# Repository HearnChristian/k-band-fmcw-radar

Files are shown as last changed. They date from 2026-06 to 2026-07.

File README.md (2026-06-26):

# K-Band FMCW Radar

A frequency-modulated continuous-wave (FMCW) radar front-end designed in KiCad —
a single-board transceiver intended for **ground-based ranging and weather /
precipitation sensing**. This repository holds the schematic capture, the
project's custom KiCad libraries, and the generated netlist. Work in progress.

## Architecture

FMCW radar works by transmitting a continuous tone whose frequency is swept
(chirped) linearly in time, then mixing the received echo against the
transmitted signal. The frequency of the resulting beat tone is proportional to
target range, so the whole signal chain is built around generating a clean,
linear chirp and digitizing the low-frequency beat note.

```
  Reference        Chirp synth        RF transceiver        Driver amp
  ┌────────┐      ┌──────────┐       ┌──────────────┐      ┌──────────┐
  │  TCXO  │─────▶│ ADF4159  │──────▶│ BGT24LTR11N16│─────▶│AMM-8211PSM│──▶ TX
  │ ref clk│      │ PLL/ramp │       │ 24 GHz Tx/Rx │      │ driver PA │
  └────────┘      └──────────┘       └──────┬───────┘      └──────────┘
                                            │ IF (beat)
                                            ▼
                       ┌──────────┐   ┌──────────┐   ┌──────────┐
                  Rx ──│ OPA1656  │──▶│ ADS8353  │──▶│ FT2232H  │──▶ USB host
                       │ IF amp   │   │ 16b ADC  │   │ USB 2.0  │
                       └──────────┘   └──────────┘   └──────────┘
```

## Key components

| Block | Part | Function |
|---|---|---|
| Chirp synthesizer | **ADF4159** | Fractional-N PLL with onboard ramp generator — produces the linear FMCW sweep |
| RF transceiver | **BGT24LTR11N16** | 24 GHz SiGe transmit/receive front-end with integrated VCO and downconversion |
| Driver amplifier | **AMM-8211PSM** | 22–57 GHz GaAs MMIC driver amp boosting the transmit chain |
| IF / baseband | **OPA1656** | Low-noise, low-distortion op-amp conditioning the beat-note signal |
| Data converter | **ADS8353** | Dual 16-bit SAR ADC sampling the IF |
| Host interface | **FT2232HL** | USB 2.0 bridge for control + data streaming |
| Reference clock | **ECS-TXO-2520MV** | TCXO frequency reference |
| Power | **TPS7A4700 / TPS7A2018 / TPS7A2033** | Ultra-low-noise LDOs for clean RF/analog rails |
| Config | **93LC56B** | EEPROM for FT2232 descriptor |

## Custom library work

The **AMM-8211PSM** driver amplifier had no vendor-supplied EDA data — only a
datasheet — so its schematic symbol and PCB footprint were built from scratch
from the Marki Microwave mechanical drawings:

```
AMM-8211PSM.kicad_sym                                          custom symbol
AMM-8211PSM.pretty/QFN-16-1EP_3x3mm_P0.5mm_EP1.1x1.1mm_Marki.kicad_mod   custom footprint
```

The footprint is a 3 × 3 mm 16-lead QFN, 0.5 mm pitch, with a 1.10 × 1.10 mm
exposed ground paddle and a 3 × 3 array of thermal vias, matching the Marki
outline drawing and pin assignment.

## Repository layout

```
Radar1.kicad_pro      KiCad project
Radar1.kicad_sch      Schematic (in progress)
Radar1.kicad_pcb      PCB layout (not yet started)
Radar1.net            Exported netlist
AMM-8211PSM.kicad_sym Custom symbol (see above)
AMM-8211PSM.pretty/   Custom footprint library
sym-lib-table         Project symbol-library table
fp-lib-table          Project footprint-library table
```

## Tools

Designed in [KiCad](https://www.kicad.org/) 9. Open `Radar1.kicad_pro` to view
the schematic.

---

*Author: Christian Hearn*

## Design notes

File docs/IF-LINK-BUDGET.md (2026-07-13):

# IF Gain vs Link Budget (Rev-F)

Sizing the OPA1656 IF stage between the BGT24LTR11 mixer and the ADS8353
(pseudo-diff vs VREF = 2.5 V, FS = ±2.5 V pk). Reproduce with
`tools/if_link_budget.py`.

## Assumptions

+6 dBm TX (BGT24 typ), 10 dBi per antenna, 1 dB per cable, 250 MHz / 1 ms
chirp (beat = 1.667 kHz/m, FFT bin 1 kHz), mixer Gc 20 dB / NF 10 dB SSB /
IP1dB −28 dBm (DS Table 4), anti-alias 49.9 Ω + 10 nF = 319 kHz.

## Gain choice: ×19 (R13/R16 = 18k, Rg = 1k)

The mixer compresses at −28 dBm input → 126 mVpk at its output. Gain
×19.9 maps that exactly onto ADC full scale, so the converter clips only
when the mixer itself is already compressing — no wasted ADC range, no
ADC-first clipping. E24 choice **×19 = 25.6 dB** (was ×11 placeholder,
which left ~5 dB of ADC range unusable).

Noise: chain noise at the ADC is 190 µVrms (269 nV/√Hz over the AA band)
vs ~44 µVrms ADC noise → solidly thermal-limited; sensitivity is set at
the mixer input and is independent of this gain within reason.

## Coupling corner: C36/C37 100 nF → 560 pF

Into the 100 kΩ VREF bias the old corner was **16 Hz** — passing the TX
leakage beat and closest clutter at full gain, which would dominate the
ADC range. 560 pF puts the corner at **2.8 kHz ≈ 1.7 m** minimum range;
the single pole also provides mild R⁴ compensation below the corner.

## Performance (per 1 kHz bin, 13 dB detection)

| Target | Range | Beat | ADC level (×19) | SNR/bin |
|---|---|---|---|---|
| person (1 m²) | 10 m | 17 kHz | 2.7 mVpk | 47 dB |
| person | 30 m | 50 kHz | 295 µVpk | 28 dB |
| car (10 m²) | 50 m | 83 kHz | 336 µVpk | 29 dB |
| car | 100 m | 167 kHz | 84 µVpk | 17 dB |
| car | 150 m | 250 kHz | 37 µVpk | 10 dB |

Detection range ≈ **70 m (person) / 125 m (car)**; the anti-alias corner
caps the instrumented range at 191 m. Sample both ADC channels at
≥640 kSPS (ADS8353 supports 700 kSPS dual).

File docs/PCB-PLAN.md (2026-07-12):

# PCB Plan — Stackup Trade & Floorplan (pre-layout)

Base: schematic `21be641` (electrically identical to Rev-C `4aef776`, netlist-verified).
Date: 2026-07-09.

## Substrate decision

Only the three 24 GHz runs (TX chain to J3, RX feed from J4) and the 1.5 GHz
divided LO care about the substrate; everything else is DC/SPI/IF.

| Option | Dk | tan δ | ~Loss @24 GHz | Z₀ tol | Verdict |
|---|---|---|---|---|---|
| All FR4 | 4.2–4.6 (uncontrolled) | ~0.020 | 0.5–0.8 dB/cm | ±8–10 % | Reject — loss + Dk uncertainty eat the PA gain budget |
| **Hybrid RO4350B (10 mil) over FR4** | 3.48 ± 0.05 | 0.0037 | 0.10–0.15 dB/cm | ±2–3 % | **Pick** — all RF is on L1/L2; FR4 below carries power/digital |
| Full RO4350B | 3.48 ± 0.05 | 0.0037 | 0.10–0.15 dB/cm | ±2–3 % | Overkill — inner layers are DC/digital |

**Stackup (≈1.5 mm, ENIG):** L1 RF/signal — RO4350B 0.254 mm — L2 solid GND —
FR4 core ≈0.9 mm — L3 power — prepreg — L4 signal/GND.
50 Ω GCPW starting point: w ≈ 0.50 mm, gap ≈ 0.25 mm (field-solve against fab stackup).

## Floorplan (board ≈ 66 × 46 mm)

- **West edge:** J3 (TX) / J4 (RX) end-launch, ≥26.5 GHz rated (2.92 mm preferred).
  U12 PA driver between U1 and J3; U1 BGT24 center-west. 24 GHz GCPW with via
  fences (pitch ≤ 0.8 mm) both sides; stitching ring around RF zone.
- **PLL:** U2 ADF4159 east of U1; loop filter tight, guarded, nothing switching
  within 5 mm; Y1 50 MHz TCXO short/direct into REFIN.
- **Center:** IF chain U1 → U3 (OPA1656 ×3) → U8 ADS8353; U15 REF5025 adjacent.
- **East edge:** U7 FT2232H, U11 12 MHz, U10 EEPROM, J1 USB-C.
- **South strip:** J2 barrel (SE) → U6 5 V LDO (+ thermal pour) → LDO row.
  U9 ADP5600 (−VGG charge pump, the only switcher) far corner from RX, LC
  post-filter to PA gate. +3V3_RF / +3V3_DIG copper split mirrors the Rev-C rail split.
- Thermal: EP via arrays under U1, U12, U6, U13.

## Blockers before placement

1. **CRITICAL — ADF4159 SPI overvoltage.** FT2232H drives CLK/DATA/LE/CE/TXDATA
   at 3.3 V; ADF4159 digital abs-max = DVDD + 0.3 V = 2.1 V (datasheet Table 4).
   MUXOUT readback (1.8 V logic → 3.3 V-bank input) is marginal in reverse.
   Fix (no new parts): power FT2232H ADBUS-bank VCCIO from +1V8 (VCCIO spec
   1.62–3.63 V), and move ADS8353 DVDD from +3V3_RF to +1V8 (also removes ADC
   digital noise from the RF rail).
2. Footprint pass: ~12 symbols unassigned; 5 libs missing from `fp-lib-table`.
3. Sync embedded symbols with libs (USB4215-03-A, AMM-8211PSM mismatch).
4. Spec barrel input 6 V nominal (≤6.5 V) or add buck before U6 — LDO drops
   (VIN−5 V) × ~0.45 A.
5. Optional: route U1 V_PTAT to a spare ADC channel for temperature telemetry.

## Verified correct in this review

PA sequencing (ADP5600 PGOOD gates +3V0_PA enable), PA bias (Vd = 3 V/175 mA =
datasheet nominal), TPS7A4700 straps (5.0 V / 3.0 V exact), FT2232 VCORE loop,
ADF4159 rail split (AVDD 3.3 / DVDD 1.8). ERC "errors" are symbol pin-type
pedantry; netlist has no floating nets.

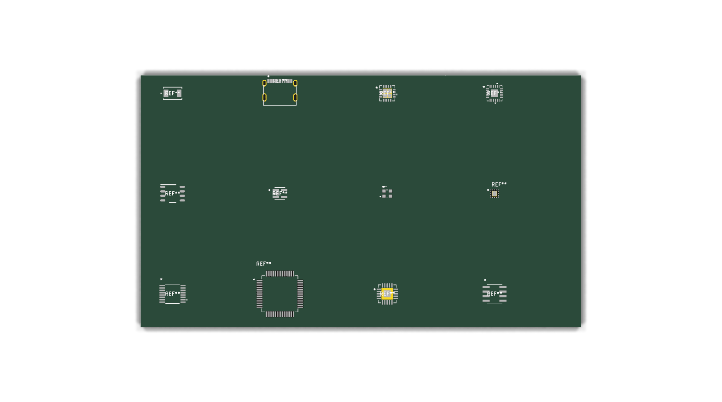
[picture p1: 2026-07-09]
docs/footprints-preview.png

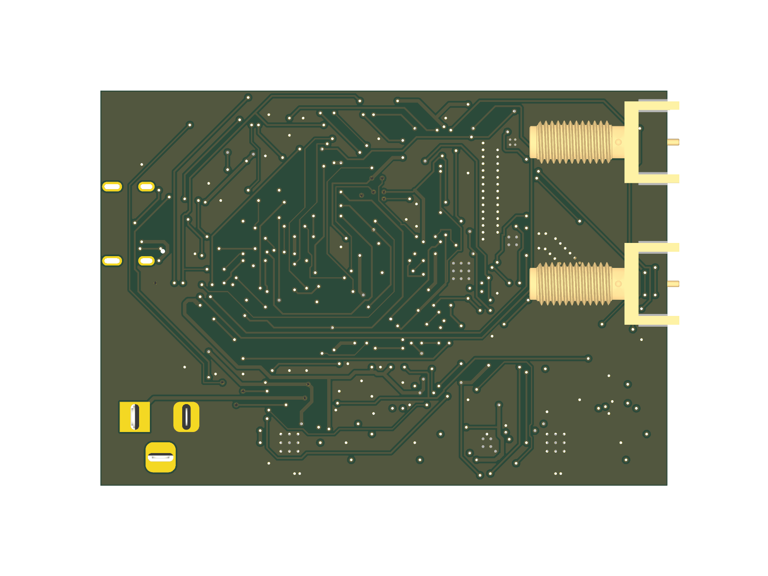
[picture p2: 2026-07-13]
docs/board-bottom.png

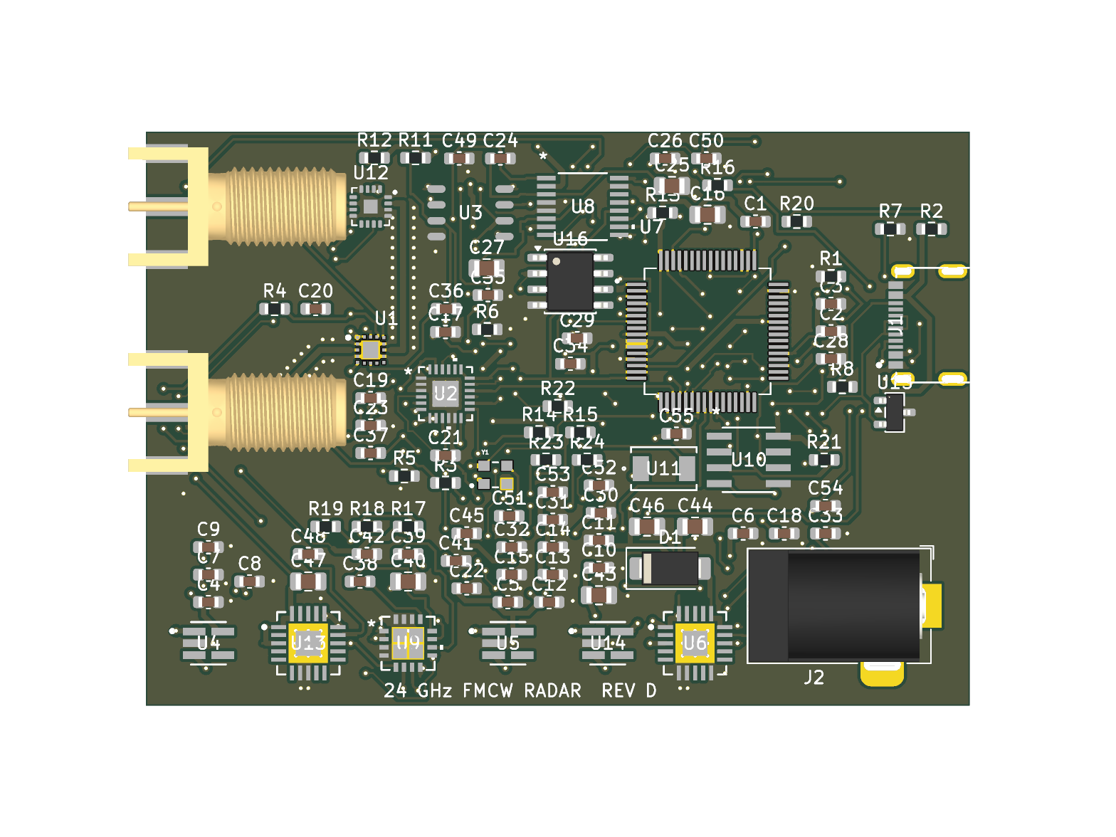
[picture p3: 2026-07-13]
docs/board-top.png

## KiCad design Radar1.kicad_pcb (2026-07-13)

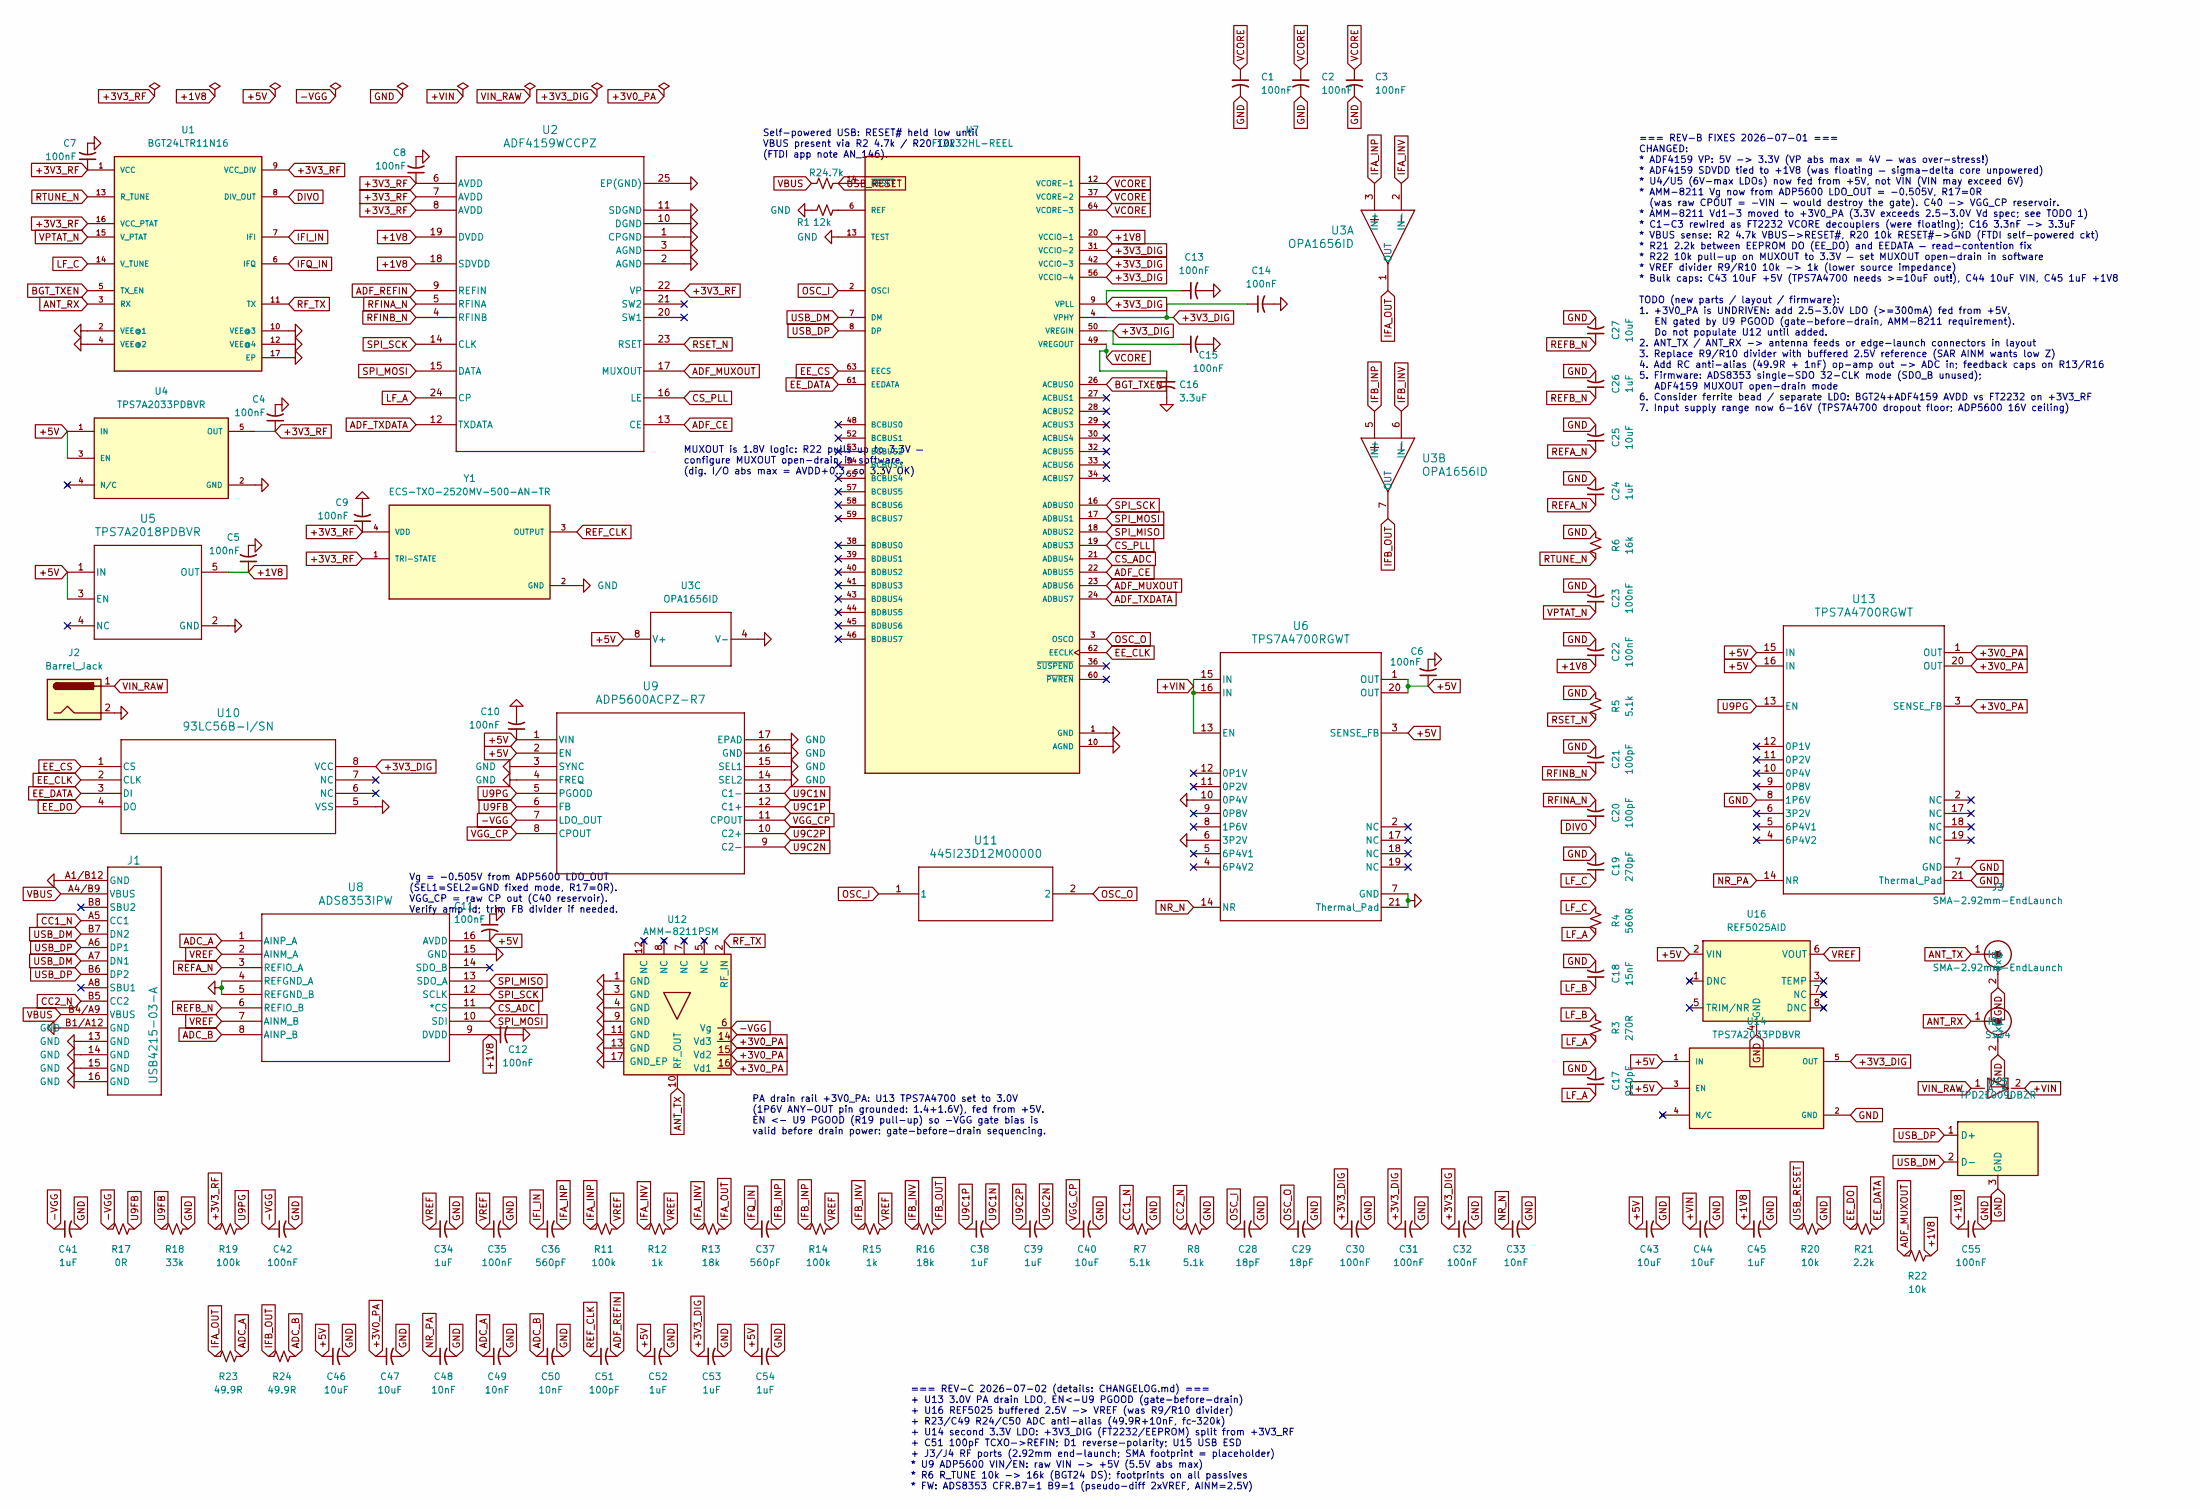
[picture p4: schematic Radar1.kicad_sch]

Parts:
C1, C2, C3, C4, C5, C6, C7, C8, C9, C10, C11, C12, C13, C14, C15, C22, C23, C30, C31, C32, C35, C42, C55: 100nF; C_0603_1608Metric
C16: 3.3uF; C_0805_2012Metric
C17: 910pF; C_0603_1608Metric
C18: 15nF; C_0603_1608Metric
C19: 270pF; C_0603_1608Metric
C20, C21, C51: 100pF; C_0603_1608Metric
C24, C26, C34, C38, C39, C41, C45, C52, C53, C54: 1uF; C_0603_1608Metric
C25, C27, C40, C43, C44, C46, C47: 10uF; C_0805_2012Metric
C28, C29: 18pF; C_0603_1608Metric
C33, C48, C49, C50: 10nF; C_0603_1608Metric
C36, C37: 560pF; C_0603_1608Metric
D1: SS34; D_SMA
J1: USB4215-03-A; CONN_8p94X6p5X3p16_12L_GCC
J2: Barrel_Jack; BarrelJack_Horizontal
J3, J4: SMA-2.92mm-EndLaunch; SMA_Amphenol_132289_EdgeMount
R1: 12k; R_0603_1608Metric
R2: 4.7k; R_0603_1608Metric
R3: 270R; R_0603_1608Metric
R4: 560R; R_0603_1608Metric
R5, R7, R8: 5.1k; R_0603_1608Metric
R6: 16k; R_0603_1608Metric
R11, R14, R19: 100k; R_0603_1608Metric
R12, R15: 1k; R_0603_1608Metric
R13, R16: 18k; R_0603_1608Metric
R17: 0R; R_0603_1608Metric
R18: 33k; R_0603_1608Metric
R20, R22: 10k; R_0603_1608Metric
R21: 2.2k; R_0603_1608Metric
R23, R24: 49.9R; R_0603_1608Metric
U1: BGT24LTR11N16; PQFN50P240X240X77-17N-V
U2: ADF4159WCCPZ; CP_24_10
U3: OPA1656ID; D0008A_N
U4, U14: TPS7A2033PDBVR; DBV0005A-IPC_A; PARTREV H
U5: TPS7A2018PDBVR; DBV0005A-IPC_A
U6, U13: TPS7A4700RGWT; RGW0020A-IPC_A
U7: FT2232HL-REEL; QFP50P1200X1200X160-64N
U8: ADS8353IPW; PW16_TEX
U9: ADP5600ACPZ-R7; CP-16-17_ADI
U10: 93LC56B-I/SN; SOIC8-N_MC_MCH
U11: 445I23D12M00000; 445I23D12M00000_CTS
U12: AMM-8211PSM; QFN-16-1EP_3x3mm_P0.5mm_EP1.1x1.1mm_Marki; MPN AMM-8211PSM-22
U15: TPD2E009DBZR; SOT-23
U16: REF5025AID; SOIC-8_3.9x4.9mm_P1.27mm
Y1: ECS-TXO-2520MV-500-AN-TR; OSC_ECS-TXO-2520MV-500-AN-TR; PARTREV 2017

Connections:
+1V8: C5.1, C12.1, C22.1, C45.1, C55.1, R22.2, U2.18 (SDVDD), U2.19 (DVDD), U5.5 (OUT), U7.20 (VCCIO-1), U8.9 (DVDD)
+3V0_PA: C47.1, U12.14 (Vd3), U12.15 (Vd2), U12.16 (Vd1), U13.1 (OUT), U13.3 (SENSE_FB), U13.20 (OUT)
+3V3_DIG: C13.1, C14.1, C15.1, C30.1, C31.1, C32.1, C53.1, U7.4 (VPHY), U7.9 (VPLL), U7.31 (VCCIO-2), U7.42 (VCCIO-3), U7.50 (VREGIN), U7.56 (VCCIO-4), U10.8 (VCC), U14.5 (OUT)
+3V3_RF: C4.1, C7.1, C8.1, C9.1, R19.1, U1.1 (VCC), U1.9 (VCC_DIV), U1.16 (VCC_PTAT), U2.6 (AVDD), U2.7 (AVDD), U2.8 (AVDD), U2.22 (VP), U4.5 (OUT), Y1.1 (TRI-STATE), Y1.4 (VDD)
+5V: C6.1, C10.1, C11.2, C43.1, C46.1, C52.1, C54.1, U3.8 (V+), U4.1 (IN), U4.3 (EN), U5.1 (IN), U5.3 (EN), U6.1 (OUT), U6.3 (SENSE_FB), U6.20 (OUT), U8.16 (AVDD), U9.1 (VIN), U9.2 (EN), U13.15 (IN), U13.16 (IN), U14.1 (IN), U14.3 (EN), U16.2 (VIN)
+VIN: C44.1, D1.2 (K), U6.13 (EN), U6.15 (IN), U6.16 (IN)
-VGG: C41.1, C42.1, R17.1, U9.7 (LDO_OUT), U12.6 (Vg)
ADC_A: C49.1, R23.2, U8.1 (AINP_A)
ADC_B: C50.1, R24.2, U8.8 (AINP_B)
ADF_CE: U2.13 (CE), U7.22 (ADBUS5)
ADF_MUXOUT: R22.1, U2.17 (MUXOUT), U7.23 (ADBUS6)
ADF_REFIN: C51.2, U2.9 (REFIN)
ADF_TXDATA: U2.12 (TXDATA), U7.24 (ADBUS7)
ANT_RX: J4.1 (In), U1.3 (RX)
ANT_TX: J3.1 (In), U12.10 (RF_OUT)
BGT_TXEN: U1.5 (TX_EN), U7.26 (ACBUS0)
CC1_N: J1.A5 (CC1), R7.1
CC2_N: J1.B5 (CC2), R8.1
CS_ADC: U7.21 (ADBUS4), U8.11 (*CS)
CS_PLL: U2.16 (LE), U7.19 (ADBUS3)
DIVO: C20.1, U1.8 (DIV_OUT)
EE_CLK: U7.62 (EECLK), U10.2 (CLK)
EE_CS: U7.63 (EECS), U10.1 (CS)
EE_DATA: R21.2, U7.61 (EEDATA), U10.3 (DI)
EE_DO: R21.1, U10.4 (DO)
GND: C1.2, C2.2, C3.2, C4.2, C5.2, C6.2, C7.2, C8.2, C9.2, C10.2, C11.1, C12.2, C13.2, C14.2, C15.2, C16.2, C17.2, C18.2, C19.2, C21.2, C22.2, C23.2, C24.2, C25.2, C26.2, C27.2, C28.2, C29.2, C30.2, C31.2, C32.2, C33.2, C34.2, C35.2, C40.2, C41.2, C42.2, C43.2, C44.2, C45.2, C46.2, C47.2, C48.2, C49.2, C50.2, C52.2, C53.2, C54.2, C55.2, J1.13 (GND), J1.14 (GND), J1.15 (GND), J1.16 (GND), J1.A1/B12 (GND), J1.B1/A12 (GND), J2.2, J3.2 (Ext), J4.2 (Ext), R1.1, R5.2, R6.2, R7.2, R8.2, R18.2, R20.2, U1.2 (VEE@1), U1.4 (VEE@2), U1.10 (VEE@3), U1.12 (VEE@4), U1.17 (EP), U2.1 (CPGND), U2.2 (AGND), U2.3 (AGND), U2.10 (DGND), U2.11 (SDGND), U2.25 (EP(GND)), U3.4 (V-), U4.2 (GND), U5.2 (GND), U6.6 (3P2V), U6.7 (GND), U6.10 (0P4V), U6.21 (Thermal_Pad), U7.1 (GND), U7.5 (GND), U7.10 (AGND), U7.11 (GND), U7.13 (TEST), U7.15 (GND), U7.25 (GND), U7.35 (GND), U7.47 (GND), U7.51 (GND), U8.4 (REFGND_A), U8.5 (REFGND_B), U8.15 (GND), U9.3 (SYNC), U9.4 (FREQ), U9.14 (SEL2), U9.15 (SEL1), U9.16 (GND), U9.17 (EPAD), U10.5 (VSS), U12.1 (GND), U12.3 (GND), U12.4 (GND), U12.9 (GND), U12.11 (GND), U12.13 (GND), U12.17 (GND_EP), U13.7 (GND), U13.8 (1P6V), U13.21 (Thermal_Pad), U14.2 (GND), U15.3 (GND), U16.4 (GND), Y1.2 (GND)
IFA_INP: C36.2, R11.1, U3.3 (IN+)
IFA_INV: R12.1, R13.1, U3.2 (IN-)
IFA_OUT: R13.2, R23.1, U3.1 (OUT)
IFB_INP: C37.2, R14.1, U3.5 (IN+)
IFB_INV: R15.1, R16.1, U3.6 (IN-)
IFB_OUT: R16.2, R24.1, U3.7 (OUT)
IFI_IN: C36.1, U1.7 (IFI)
IFQ_IN: C37.1, U1.6 (IFQ)
LF_A: C17.1, R3.1, R4.1, U2.24 (CP)
LF_B: C18.1, R3.2
LF_C: C19.1, R4.2, U1.14 (V_TUNE)
NR_N: C33.1, U6.14 (NR)
NR_PA: C48.1, U13.14 (NR)
unnamed: R1.2, U7.6 (REF)
OSC_I: C28.1, U7.2 (OSCI), U11.1
OSC_O: C29.1, U7.3 (OSCO), U11.2
REFA_N: C24.1, C25.1, U8.3 (REFIO_A)
REFB_N: C26.1, C27.1, U8.6 (REFIO_B)
REF_CLK: C51.1, Y1.3 (OUTPUT)
RFINA_N: C20.2, U2.5 (RFINA)
RFINB_N: C21.1, U2.4 (RFINB)
RF_TX: U1.11 (TX), U12.2 (RF_IN)
RSET_N: R5.1, U2.23 (RSET)
RTUNE_N: R6.1, U1.13 (R_TUNE)
SPI_MISO: U7.18 (ADBUS2), U8.13 (SDO_A)
SPI_MOSI: U2.15 (DATA), U7.17 (ADBUS1), U8.10 (SDI)
SPI_SCK: U2.14 (CLK), U7.16 (ADBUS0), U8.12 (SCLK)
U9C1N: C38.2, U9.13 (C1-)
U9C1P: C38.1, U9.12 (C1+)
U9C2N: C39.2, U9.9 (C2-)
U9C2P: C39.1, U9.10 (C2+)
U9FB: R17.2, R18.1, U9.6 (FB)
U9PG: R19.2, U9.5 (PGOOD), U13.13 (EN)
USB_DM: J1.A7 (DN1), J1.B7 (DN2), U7.7 (DM), U15.2 (D-)
USB_DP: J1.A6 (DP1), J1.B6 (DP2), U7.8 (DP), U15.1 (D+)
USB_RESET: R2.2, R20.1, U7.14 (~RESET)
VBUS: J1.A4/B9 (VBUS), J1.B4/A9 (VBUS), R2.1
VCORE: C1.1, C2.1, C3.1, C16.1, U7.12 (VCORE-1), U7.37 (VCORE-2), U7.49 (VREGOUT), U7.64 (VCORE-3)
VGG_CP: C40.1, U9.8 (CPOUT), U9.11 (CPOUT)
VIN_RAW: D1.1 (A), J2.1
VPTAT_N: C23.1, U1.15 (V_PTAT)
VREF: C34.1, C35.1, R11.2, R12.2, R14.2, R15.2, U8.2 (AINM_A), U8.7 (AINM_B), U16.6 (VOUT)

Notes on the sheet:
Vg = -0.505V from ADP5600 LDO_OUT (SEL1=SEL2=GND fixed mode, R17=0R). VGG_CP = raw CP out (C40 reservoir). Verify amp Id; trim FB divider if needed.
=== REV-C 2026-07-02 (details: CHANGELOG.md) === + U13 3.0V PA drain LDO, EN<-U9 PGOOD (gate-before-drain) + U16 REF5025 buffered 2.5V -> VREF (was R9/R10 divider) + R23/C49 R24/C50 ADC anti-alias (49.9R+10nF, fc~320k) + U14 second 3.3V LDO: +3V3_DIG (FT2232/EEPROM) split from +3V3_RF + C51 100pF T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
Self-powered USB: RESET# held low until VBUS present via R2 4.7k / R20 10k (FTDI app note AN_146).
=== REV-B FIXES 2026-07-01 === CHANGED: * ADF4159 VP: 5V -> 3.3V (VP abs max = 4V — was over-stress!) * ADF4159 SDVDD tied to +1V8 (was floating — sigma-delta core unpowered) * U4/U5 (6V-max LDOs) now fed from +5V, not VIN (VIN may exceed 6V) * AMM-8211 Vg now from ADP5600 LDO_OUT = -0.505V, R17=0R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
MUXOUT is 1.8V logic: R22 pulls up to 3.3V — configure MUXOUT open-drain in software. (dig. I/O abs max = AVDD+0.3, so 3.3V OK)
PA drain rail +3V0_PA: U13 TPS7A4700 set to 3.0V (1P6V ANY-OUT pin grounded: 1.4+1.6V), fed from +5V. EN <- U9 PGOOD (R19 pull-up) so -VGG gate bias is valid before drain power: gate-before-drain sequencing.

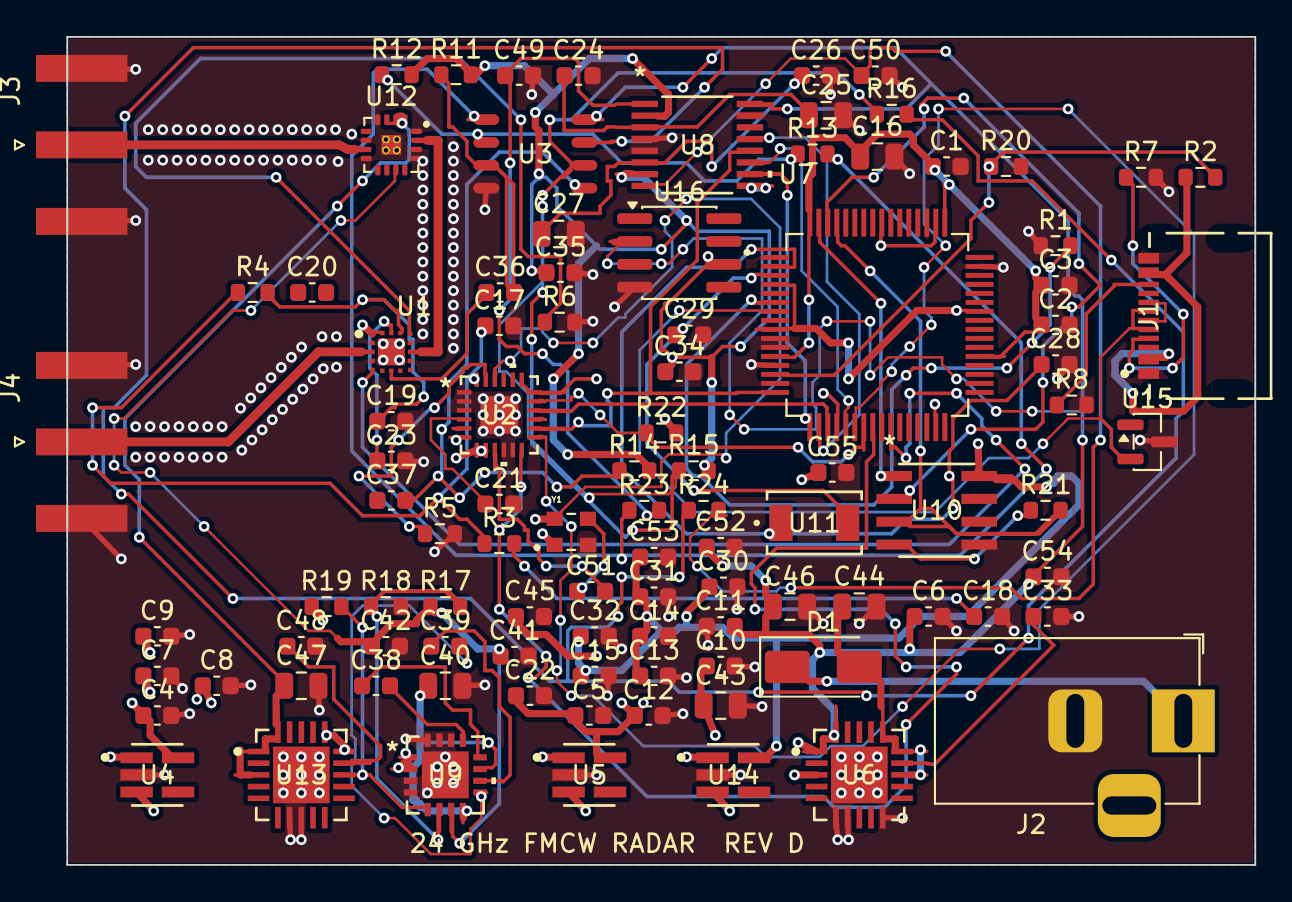
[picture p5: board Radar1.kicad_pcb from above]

Board: 4 copper layers, 66.0 x 46.0 mm, 99 parts (0 on the bottom side), 68 nets.

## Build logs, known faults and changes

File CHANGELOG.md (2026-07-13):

# Changelog

## Board bring-up — 2026-07-09

`Radar1.kicad_pcb` generated (text-built from netlist + `docs/PCB-PLAN.md`
floorplan; generator in `tools/board_gen.py`):

- **4-layer hybrid stackup** defined: F.Cu / RO4350B 0.254 mm (εr 3.48,
  tanδ 0.0037) / In1.Cu GND / FR4 0.9 mm / In2.Cu PWR / FR4 0.2 mm / B.Cu,
  ENIG finish, 1.545 mm total. All 24 GHz returns reference In1.Cu directly
  under the Rogers layer.
- **Board 60 × 42 mm**, outline + title silk. All 99 components placed:
  ICs/connectors at floorplan coordinates (RF west, PLL center, digital east,
  power south), passives auto-packed beside their owner ICs (netlist-driven
  ownership, bbox collision packing).
- **Net classes**: RF (0.5 mm track) for ANT_TX/ANT_RX/RF_TX, PWR (0.4 mm),
  Default clearance 0.15 mm (vendor fine-pitch QFNs have 0.175 mm pad gaps).
- **DRC: zero placement violations.** Remaining: 293 unconnected (unrouted —
  next phase) and 10 copper-edge items on J3/J4, expected by design: the
  Amphenol edge-launch pads intentionally overlap the board edge (standard
  waiver; the placeholder SMAs get real 2.92 mm launches before fab).
- Render: `docs/board-placement-top.png`.

Next: GCPW RF routing (w 0.50 / gap 0.25 mm + via fences), power pours, SPI.

## Footprint pass — 2026-07-09

Every IC/connector footprint is now assigned and resolvable; layout is unblocked.

- New project library **`RadarFP.pretty`** (registered in `fp-lib-table`) with 12
  vendor/UltraLibrarian footprints recovered from the part archives in
  `~/Downloads` (they had been downloaded with the symbols but never installed):
  BGT24 PQFN-16, ADF4159 CP-24-10, ADP5600 CP-16-17, ADS8353 PW-16,
  OPA1656 D-8, TPS7A20 DBV-5, TPS7A4700 RGW-20 (IPC_A variant — the MFG variant
  splits the EP into 10 separately numbered tiles and breaks pin mapping),
  FT2232H LQFP-64, 93LC56B SOIC-8, CTS 445 crystal, ECS-TXO-2520MV, GCT USB4215.
- All pad numbering validated against schematic symbol pins (incl. EP numbers:
  ADF4159 EP=25, ADP5600 EP=17, BGT24 EP=17); dimensions sanity-checked against
  package tables; render preview in `docs/footprints-preview.png`.
- U4/U14 (TPS7A2033, SOT-23-5/DBV) repointed to the DBV footprint — the
  previously referenced `TPS7A2033PDBVR:SOT95P280X145-5N` never existed on disk
  and the downloaded TPS7A2033 archive was the wrong package variant (DQN).
- Stray `Designator*` silkscreen text removed from the DBV and RGW footprints.
- Netlist connectivity verified unchanged; ERC footprint_link_issues 17 → 0.

## Rev D — 2026-07-09

SPI level-domain fix (found in pre-layout review; ADF4159 DS Rev E, Table 4).

### Problem
FT2232H drove ADF4159 CLK/DATA/LE/CE/TXDATA at 3.3 V logic, but the ADF4159
digital absolute maximum is DVDD + 0.3 V = 2.1 V — a 5-pin abs-max violation.
MUXOUT readback (1.8 V logic into a 3.3 V-referenced input) was marginal in
the reverse direction.

### Changed (zero new part types)
- **U7 pin 20 (VCCIO, ADBUS bank)** `+3V3_DIG` → `+1V8`. The ADBUS SPI bank now
  runs at 1.8 V natively (FT2232H VCCIO spec: 1.62–3.63 V, per FTDI AN_146).
  Other VCCIO banks (pins 31/42/56) stay at 3.3 V — EEPROM interface unchanged.
- **U8 pin 9 (ADS8353 DVDD)** `+3V3_RF` → `+1V8` (DVDD spec 1.65–3.6 V). The ADC
  shares the ADBUS SPI bus, so its I/O follows the 1.8 V domain — and this
  removes ADC digital switching noise from the RF/analog 3.3 V rail (C12
  decoupler rides along).
- **R22 (MUXOUT pull-up)** `+3V3_DIG` → `+1V8`. Open-drain MUXOUT plan from
  Rev B still applies, now pulling to the correct domain.
- **C55 100 nF** added on `+1V8` — local decoupling for the re-domained VCCIO
  bank (+1V8 previously had only C5/C22/C45 near U5/U2).

Verified by netlist regression (exact 5-pin expected transform, nothing else
moved) and ERC (identical message set before/after). +1V8 load additions are
~10–20 mA against TPS7A2018 headroom.

## Rev C — 2026-07-02

Functional-gap pass: every block needed for a working board (except antenna
feeds) is now present and driven.

### Added
- **U13 (TPS7A4700)** — 3.0 V PA drain LDO for the AMM-8211 (`+3V0_PA` was an
  undriven net). Output set by grounding the 1P6V ANY-OUT pin (1.4 + 1.6 V).
  Fed from +5 V; **EN driven by U9 (ADP5600) PGOOD** so the −0.5 V gate bias is
  established before drain power: gate-before-drain sequencing for the GaAs
  HEMT. AMM-8211 draws 175 mA typ (datasheet EC table, Vd = 3 V); the LDO is
  good for 1 A. C46/C47 input/output caps, C48 noise-reduction cap.
- **U16 (REF5025)** — buffered precision 2.5 V driving `VREF`. Replaces the
  R9/R10 1 kΩ divider: ADS8353 AINM inputs must sit within VREF ± 0.1 V and are
  sampled, so they need a low-impedance source, not a 500 Ω divider. C54 supply
  bypass; existing C34/C35 serve as output caps (REF50xx prefers 1–1.5 Ω ESR —
  verify, or add ~1 Ω in series at layout).
- **R23/C49, R24/C50** — anti-alias / charge-reservoir RC (49.9 Ω + 10 nF C0G,
  fc ≈ 320 kHz) between the OPA1656 outputs and ADS8353 AINP_A/B
  (new nets `ADC_A`/`ADC_B`).
- **U14 (TPS7A2033)** — second 3.3 V LDO creating `+3V3_DIG` for the FT2232
  (VCCIO ×4, VPHY, VPLL, VREGIN), EEPROM, and the MUXOUT pull-up, with
  C13–C15/C30–C32 moved over. `+3V3_RF` now feeds only ADF4159, BGT24LTR11 and
  the TCXO. Previously one 300 mA LDO carried ~230–280 mA of combined load and
  put USB switching noise on the PLL/VCO rail.
- **C51 (100 pF)** — AC coupling between the TCXO output and ADF4159 REFIN
  (new net `ADF_REFIN`), per ADF4159 reference-input practice.
- **D1 (SS34)** — reverse-polarity Schottky after the barrel jack (new net
  `VIN_RAW`). Recommended supply ~6 V: at 12 V input, U6 would dissipate ~4 W.
- **U15 (TPD2E009)** — USB ESD protection array on USB_DP/USB_DM.
- **J3/J4** — board-side RF ports for `ANT_TX`/`ANT_RX`. At 24 GHz use 2.92 mm
  (K) end-launch connectors; the assigned stock SMA edge-mount footprint is a
  **placeholder** to be replaced during layout. No series DC blocks needed —
  the AMM-8211 RF ports are internally DC-blocked (Marki datasheet).

### Changed
- **U9 (ADP5600) VIN/EN moved from raw VIN to +5 V.** Absolute max input is
  5.5 V while the TPS7A4700 needs > 5.3 V input to regulate — no valid supply
  voltage satisfied both. Input bypass C10 moved with it.
- **R6 (BGT24LTR11 R_TUNE) 10 k → 16 k** — datasheet spec condition for the
  24.05–24.25 GHz VCO range.
- Footprints assigned to **all** passives (0603; 10 µF/3.3 µF in 0805) and J2.
- Sheet A4 → A3 (content overflowed the A4 border).
- New symbols live in the project library `RadarExtra.kicad_sym`.

### Firmware notes
- ADS8353: CFR.B7 = 1, CFR.B9 = 1 (pseudo-differential, 2×VREF range,
  AINM = 2.5 V, AINP swings 0–5 V); single-SDO 32-CLK mode.
- ADF4159: configure MUXOUT as open-drain (R22 pulls up to 3.3 V digital rail).

### Still open
- Antenna feed line design + real 2.92 mm end-launch footprints (layout).
- PLL loop filter values are placeholders — recompute from Kvco/Icp/N.
- IF gain ×11 is a placeholder pending link-budget analysis.
- REF5025 output-cap ESR check (see above).

## Rev B — 2026-07-01

Datasheet-verification pass over the fully wired schematic (ERC 50 → 11).

- ADF4159 VP 5 V → 3.3 V (4 V abs max — was over-stressed); SDVDD tied to +1V8
  (was floating).
- U4/U5 (6 V-max LDOs) re-fed from +5 V instead of raw VIN.
- AMM-8211 Vg moved from raw charge-pump output to the ADP5600 regulated
  −0.505 V LDO output (SEL1 = SEL2 = GND fixed mode, R17 → 0 R); Vd1–3 moved to
  new `+3V0_PA` net (LDO added in Rev C).
- FT2232: C1–C3 rewired as VCORE decouplers (100 nF), C16 3.3 nF → 3.3 µF,
  VBUS sense divider (R2/R20) into RESET# for self-powered configuration,
  R21 EEPROM DO isolation, R22 MUXOUT pull-up.
- Bulk caps C43–C45; VREF divider stiffened (superseded by REF5025 in Rev C);
  29 no-connect flags; GND moved onto J1 B1/A12 (was 3.81 mm off-pin).

## Rev A — 2026-06-26

Initial full wiring: 8 → 58 connected nets, 43 components added. Regulators,
TCXO reference, PLL loop filter + DIV_OUT feedback, TX → AMM-8211, IF stage,
SPI/USB/EEPROM, ADP5600 → −VGG gate bias.

## Rev-E (2026-07-13)

- PLL loop filter redesigned from datasheet parameters (docs/PLL-LOOP-FILTER.md):
  topology fix (R4 input moved from R3/C18 junction to CPOUT — the captured
  ladder had no stabilizing zero and could not lock), values 910pF/270R/15nF/
  560R/270pF for fc=146kHz, PM=52deg at Kvco typ, Icp 2.5mA.
- Board updated surgically: R4.1 re-netted, LF_A/LF_B rerouted, values synced.

## Rev-F (2026-07-13)

- IF stage sized against the link budget (docs/IF-LINK-BUDGET.md):
  gain x11 -> x19 (R13/R16 10k -> 18k) aligning mixer IP1dB with ADC full
  scale; coupling C36/C37 100nF -> 560pF moves the HPF corner 16 Hz ->
  2.8 kHz (1.7 m min range, rejects TX-leakage beat). Values only.

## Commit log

2026-06-25 Initial commit: X-band FMCW radar schematic capture (WIP)
    24 GHz FMCW radar front-end in KiCad: ADF4159 chirp synthesizer ->
    BGT24LTR11 transceiver -> AMM-8211PSM driver amp -> OPA1656 IF ->
    ADS8353 ADC -> FT2232H USB, with TCXO reference and TPS7A LDOs.
    Includes a custom-built KiCad symbol + footprint for the Marki
    AMM-8211PSM driver amplifier (no vendor EDA data existed).
    [Radar1.kicad_pcb, Radar1.kicad_sch]
2026-06-26 Schematic layout cleanup and resistor value convention
    Manual rearrangement/placement pass in KiCad; resistor values switched to
    standard k/M convention (e.g. 12kOHMS -> 12k). Netlist verified: 76
    components, 58 connected nets unchanged, no annotation errors.
    [Radar1.kicad_sch]
2026-07-02 Rev-B fix pass: power/bias corrections from datasheet review
    - ADF4159 VP 5V->3.3V (4V abs max), SDVDD tied to +1V8
    - U4/U5 6V-max LDOs re-fed from +5V instead of raw VIN
    - AMM-8211 Vg moved to ADP5600 regulated -0.505V LDO output;
    Vd1-3 moved to new +3V0_PA net (drain LDO TBD, PGOOD-sequenced)
    - FT2232: C1-C3 as VCORE decouplers, VBUS sense divider to RESET#,
    EEPROM DO isolation (R21), MUXOUT pull-up to 3.3V (R22)
    - Bulk caps C43-C45, VREF divider stiffened, 29 no-connect flags
    - ERC 50 -> 11 errors (rest symbol pin-type quirks + 2 intentional)
    Changelog/TODO block on sheet at (318,15).
    [Radar1.kicad_sch]
2026-07-02 Rev-C: complete functional gaps — PA supply, VREF buffer, rail split
    Blockers fixed:
    - U13 TPS7A4700 3.0V PA drain LDO drives +3V0_PA (was undriven);
    EN <- U9 PGOOD for gate-before-drain sequencing (AMM-8211 175mA typ)
    - U9 ADP5600 re-fed from +5V (5.5V abs max vs raw VIN conflict)
    - J3/J4 board-side RF ports for ANT_TX/ANT_RX (2.92mm end-launch;
    stock SMA footprint is a layout placeholder)
    - R6 R_TUNE 10k -> 16k per BGT24LTR11 spec for 24.05-24.25GHz VCO
    Robustness:
    - U16 REF5025 buffered 2.5V -> VREF, replaces R9/R10 divider
    (ADS8353 AINM needs low-Z source; CFR.B7=1 B9=1 pseudo-diff 2xVREF)
    - R23/C49 R24/C50 anti-alias RCs (49.9R+10nF) ahead of ADS8353
    - U14 TPS7A2033: +3V3_DIG (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
    [Radar1.kicad_sch]
2026-07-09 Re-serialize schematic under current KiCad (no electrical change; netlist-verified identical to Rev-C)
    [Radar1.kicad_sch]
2026-07-09 Footprint pass: RadarFP.pretty with 12 validated vendor footprints, all parts assigned
    ERC footprint_link_issues 17->0; netlist connectivity unchanged.
    [Radar1.kicad_sch]
2026-07-12 RF routing: GCPW TX/RX lines, 4-layer GND/PWR zones, EP thermal vias
    - tools/route_pcb.py (pcbnew API): F.Cu/In1/B.Cu GND zones + In2 +5V zone,
    EP thermal via arrays, 24 GHz GCPW (0.5 mm / 0.25 gap) with GND via fences
    - Neck-down to pad width at QFN pad exits (0.5 mm line vs 0.5 mm-pitch pads)
    - Via fence self-avoidance against RF copper; RF corridor keepouts in board_gen
    so auto-slotted passives stay out of the GCPW paths
    - AMM-8211 footprint: EP thermal vias 9@0.3mm -> 4@0.6mm pitch (fab-safe webs)
    - DRC: copper clean; remaining = 172 unconnected (signals, next phase),
    10 J3/J4 edge-launch waivers, silk cosmetics
    [Radar1.kicad_pcb]
2026-07-12 Phase C routing: A* signal/power router, In2 split planes, board 66x46
    tools/route_signals.py: 0.2mm-grid A* over F.Cu/B.Cu with through-vias.
    - escape stubs on fine-pitch ICs, escape-limited nets routed first
    - In2 becomes a split plane: +3V3_RF west / +1V8 center / +3V3_DIG east
    over the +5V base fill; rail pads stitch down with vias, stragglers
    routed as tracks; GND stitching to In1 near every ground pad
    - rip-up & reroute for sealed legs; geometric heal pass reconnects
    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
    [Radar1.kicad_pcb]
2026-07-12 Routing: thin-width heal class (0.15mm), regenerate at best config
    DRC: 28 unconnected items (18 net splits) remain, concentrated at the
    RF-pocket wall crossings (-VGG, DIVO, LF_C, +3V3_RF at U1/U12), the U2
    east SPI column, U7 west, and J1. Copper otherwise clean: no clearance,
    short, or hole errors; 10 J3/J4 edge-launch waivers by design.
    Next: hand-finish the last splits (probe-driven, or KiCad GUI).
    [Radar1.kicad_pcb]
2026-07-13 Finisher pass 1: exact via-feasibility map, GND re-stitch; 28 -> 25 unconnected
    [Radar1.kicad_pcb]
2026-07-13 Finisher: transactional rip-heal, corner-safe pad model; 25 -> 23 unconnected
    [Radar1.kicad_pcb]
2026-07-13 Finisher iteration: 23 -> 22 unconnected; 6 capacity-limited nets remain
    Remaining splits: +3V3_RF (U1.9 pocket), ADF_TXDATA, CS_ADC, SPI_MOSI
    (U2->U7 SPI corridor at capacity), DIVO (U1 south escape slot), RFINA_N
    (pocket wall). These need a placement nudge or GUI routing; every
    rip/swap transaction rolls back because the corridors are full.
    [Radar1.kicad_pcb]
2026-07-13 Remove probe scripts; regional rip+move+reroute experiment also net-negative
    22 unconnected / 6 nets stands as the text-toolchain fixpoint. The last
    six (U1-south slot, U2->U7 SPI corridor) need interactive routing.
2026-07-13 Rev-F: IF gain and coupling corner from link budget
    Mixer IP1dB (-28 dBm in, 126 mVpk out) mapped onto ADS8353 full scale:
    gain x11 -> x19 (R13/R16 = 18k). Coupling C36/C37 100nF -> 560pF: HPF
    corner 16 Hz -> 2.8 kHz (min range 1.7 m, kills TX-leakage beat at full
    gain). Chain is thermal-noise-limited (190 uV chain vs 44 uV ADC);
    detection ~70 m person / ~125 m car per 1 kHz bin at 13 dB; AA corner
    limits instrumented range to 191 m. tools/if_link_budget.py reproduces.
    Netlist-regression: value-only change, topology untouched.
    [Radar1.kicad_pcb, Radar1.kicad_sch]
